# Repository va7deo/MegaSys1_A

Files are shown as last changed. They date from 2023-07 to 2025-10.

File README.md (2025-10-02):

# Jaleco Mega System 1 A FPGA Implementation

FPGA compatible core of Jaleco's Mega System 1 A (P-47 based) arcade hardware for [**MiSTerFPGA**](https://github.com/MiSTer-devel/Main_MiSTer/wiki) written by [**Erin Olafson**] with assistance from [**atrac17**](https://github.com/atrac17). Verified against a authentic P-47: The Freedom Fighter PCB purchased by [**atrac17**](https://github.com/atrac17).

The intent is for this core to be a 1:1 playable implementation of the Mega System 1 A arcade hardware. Currently in **beta state**, this core is in active development. Additional Mega System 1 arcade titles will be in separate repositories (Mega System 1 Rev Z/B/C).

<br>
<p align="center">

</p>

## Supported Titles (Type-A)

| Title | PCB<br>Number | Encrypted<br>Program | MCU | Status | Released |
|---|---|---|-----|---|---|
| [**P-47: The Freedom Fighter**](FILLME) | MB8844<br><br>MB8843 | N/A | N/A | **Implemented** | **20230701** |
| [**Kick Off - Jaleco Cup**](FILLME) | MB8844 | N/A | N/A | **Implemented / W.I.P** | No |
| [**Shingen Samurai-Fighter / Takeda Shingen**](FILLME) | MB8844 | Yes | N/A | **Implemented / W.I.P** | No |
| [**Ninja Kazan / Iga Ninjyutsuden**](FILLME) | MB8845 | Yes | Yes | **Implemented** | **20230923** |
| [**The Astyanax / The Lord of King**](FILLME) | MB8844<br><br>MB8845 | Yes | Yes | **Implemented** | **20230701** |
| [**Hachoo!**](FILLME) | MB8845 | Yes | Yes | **Implemented** | **20240101** |
| [**Jitsuryoku!! Pro Yakyuu**](FILLME) | MBMO2A | Yes | Yes | **Implemented** | **20240106** |
| [**Plus Alpha**](FILLME) | MB8845 | Yes | Yes | **Implemented** | **20240106** |
| [**Saint Dragon**](FILLME) | MB8845 | Yes | Yes | **Implemented** | **20230715** |
| [**Rod-Land**](https://en.wikipedia.org/wiki/Rod_Land) | MBMO2A<br><br>MB8845 | Yes | N/A | **Implemented** | **20230513** |
| [**Phantasm**](FILLME) | MB8845 | Yes | N/A | **Implemented** | **20230708** |
| [**E.D.F: Earth Defense Force (Prototpe)**](FILLME) | W.I.P | Yes | N/A | **Implemented** | **20240101** |
| [**In Your Face (Prototpe)**](FILLME) | W.I.P | Yes | N/A | **Implemented** | **20240101** |
| [**Soldam**](FILLME) | W.I.P | Yes | N/A | **Implemented** | **20230519** |

## External Modules

| Module | Function | Author |
|---|---|---|
| [**fx68k**](https://github.com/ijor/fx68k) | [**Motorola 68000 CPU**](https://en.wikipedia.org/wiki/Motorola_68000) | Jorge Cwik |
| [**fx68k**](https://github.com/ijor/fx68k) | [**Motorola 68000 CPU**](https://en.wikipedia.org/wiki/Motorola_68000) | Jorge Cwik |
| [**jt51**](https://github.com/jotego/jt51) | [**Yamaha YM2151**](https://en.wikipedia.org/wiki/Yamaha_YM2151) | Jose Tejada |
| [**jt6295**](https://github.com/jotego/jt6295) | [**OKI MSM6295**](https://dtsheet.com/doc/957023/oki-m6295) | Jose Tejada |
| [**jt6295**](https://github.com/jotego/jt6295) | [**OKI MSM6295**](https://dtsheet.com/doc/957023/oki-m6295) | Jose Tejada |
| [**yc_out**](https://github.com/MikeS11/MiSTerFPGA_YC_Encoder) | [**Y/C Video Module**](https://en.wikipedia.org/wiki/S-Video) | Mike Simone |
| [**mem**](https://github.com/MiSTer-devel/Arcade-Rygar_MiSTer/tree/master/src/mem) | SDRAM Controller / Rom Downloader | Josh Bassett, modified by Erin Olafson |
| [**core_template**](https://github.com/MiSTer-devel/Template_MiSTer) | MiSTer Framework Template | sorgelig, modified by Erin Olafson / atrac17 |

# Known Issues / Tasks

- ~~OKI playback; correct samples (ROM board dependent)~~  **[Issue]**  

- Mosaic OBJ effects verify against PCB (P-47 JALECO logo)  **[Task]**
- OBJ Scroll effects verify against PCB (P-47 trail effect)  **[Task]**
- ~~Screen flip implementation~~  **[Task]**  
- ~~Verify H-FLIP / V-FLIP for screen flip against PCB~~  **[Task]**
- ~~Program CPU overclock toggle~~  **[Task]**  
- ~~OPM / ADPCM audio mix toggles~~  **[Task]**  
- ~~Verify analog timings from MB8842 mother board~~  **[Task]**  
- ~~Measure HBL, VBL, H-SYNC, and V-SYNC timings from MB8842 mother board~~  **[Task]**  
- ~~64-Bit SDRAM controller access for sprites  **[Task]**~~  

# PCB Check List

## Clock Information

| H-Sync | V-Sync | Source | PCB<br>Number |
|---|---|---|---|
| 15.625kHz | 56.205035 | DSLogic+  | **MB8842** |

## Crystal Oscillators

| Freq (MHz) | Use | PCB<br>Number |
|---|---|---|
| 4.000 MHz  | OKI MSM6295 / MCU CLKS (4 MHz) | **ROM Board<br>(See PCB Number)** |
| 7.000 MHz  | M68000 AUDIO CLOCK (7MHz)<br>YM2151 CLK (3.5 MHz) | **MB8842** |
| 12.000 MHz | M68000 CPU CLK (6 MHz)<br>Pixel CLK (6 MHz) | **MB8842** |

**Pixel clock:** 6.00 MHz

**Estimated geometry:**

    384 pixels/line  
  
    278 lines/frame  

## Main Components

| Chip | Use | PCB Number |
|---|---|---|
| [**Motorola 68000 CPU**](https://en.wikipedia.org/wiki/Motorola_68000) | Main CPU | **MB8842** |
| [**Motorola 68000 CPU**](https://en.wikipedia.org/wiki/Motorola_68000) | Audio CPU | **MB8842** |
| [**Yamaha YM2151**](https://en.wikipedia.org/wiki/Yamaha_YM2151) | OPM Sound | **MB8842** |
| [**OKI MSM6295**](https://dtsheet.com/doc/957023/oki-m6295) | ADPCM Sound | **ROM Board<br>(See PCB Number)** |
| [**OKI MSM6295**](https://dtsheet.com/doc/957023/oki-m6295) | ADPCM Sound | **ROM Board<br>(See PCB Number)** |

### Custom Components

| Chip | Function |
| ---|---|
| **NEC D65005GB200** | Custom Gate-Array / OBJ  |
| **NEC D65005GB249** | Custom Gate-Array / SYNC |
| **NEC D65012GF303** | Custom Gate-Array / VCTR |
| **NEC D65012GF307** | Custom Gate-Array / SCPT | <br>

# Core Features

### Refresh Rate Compatibility Option

- Video timings can be modified if you experience sync issues with CRT or modern displays; this will alter gameplay from it's original state.

| Refresh Rate | Timing Parameter | HTOTAL | VTOTAL |
|---|---|---|---|
| 15.63kHz / 56.2Hz | MB8842 | 384 | 278 |
| 15.63kHz / 59.4Hz | NTSC (Closest Spec)  | 384 | 263 |

- MAME information for timing parameters is incorrect.

| Refresh Rate | Timing Parameter | HTOTAL | VTOTAL |
|---|---|---|---|
| 14.77kHz / 56.2Hz | MAME | 406 | 263 |

### P1/P2 Input Swap Option

- There is a toggle to swap inputs from Player 1 to Player 2. This only swaps inputs for the joystick, it does not effect keyboard inputs.

### Audio Options

- There is a toggle for mixing audio from mono to stereo; MB8842 had this option via dipswitch.

- There are toggles to disable playback of OPM and ADPCM audio or raise the mixing volume the OPM and ADPCM audio channels.

### Overclock Options

- There is a toggle to increase the M68000 frequency from 6MHz to 7.2MHz; this will alter gameplay from it's original state addressing native slowdown of gameplay.

### Native Y/C Output

- Native Y/C ouput is possible with the [**analog I/O rev 6.1 pcb**](https://github.com/MiSTer-devel/Main_MiSTer/wiki/IO-Board). Using the following cables, [**HD-15 to BNC cable**](https://www.amazon.com/StarTech-com-Coax-RGBHV-Monitor-Cable/dp/B0033AF5Y0/) will transmit Y/C over the green and red lines. Choose an appropriate adapter to feed [**Y/C (S-Video)**](https://www.amazon.com/MEIRIYFA-Splitter-Extension-Monitors-Transmission/dp/B09N19XZJQ) to your display.

### H/V Adjustments

- There are two H/V toggles, H/V-sync positioning adjust and H/V-sync width adjust. Positioning will move the display for centering on CRT display. The sync width adjust can be used to for sync issues (rolling, flagging etc) without modifying the video timings.

### Scandoubler Options

- Additional toggle to enable the scandoubler without changing ini settings and new scanline option for 100% is available, this draws a black line every other frame. Below is an example.

<table><tr><th>Scandoubler Fx</th><th>Scanlines 25%</th><th>Scanlines 50%</th><th>Scanlines 75%</th><th>Scanlines 100%</th><tr><td><br> <p align="center"></td><td><br> <p align="center"></td><td><br> <p align="center"></td><td><br> <p align="center"></td><td><br> <p align="center"></td></tr></table> <br>

# PCB Information / Control Layout

| Title | Joystick | Service Menu | Dip Switches | Shared Controls | Dip Default | PCB Information |
|---|---|---|---|---|---|---|
| **P-47: The Freedom Fighter** | 8-Way | **Service Menu** | **Dip Sheet** | Co-Op | N/A | Coming soon |
| **Ninja Kazan / Iga Ninjyutsuden** | 8-Way | **Service Menu** | **Dip Sheet** | Turn Based | N/A | Coming soon |
| **Phantasm** | 8-Way | **Service Menu** | **Dip Sheet** | Turn Based | N/A | Coming soon |
| **Saint Dragon** | 8-Way | **Service Menu** | **Dip Sheet** | Turn Based | N/A | Coming soon |
| **The Astyanax / The Lord of King** | 8-Way | **Service Menu** | **Dip Sheet** | Co-Op | N/A | Coming soon |
| **Rod-Land** | 8-Way | [**Service Menu**](https://github.com/va7deo/MegaSys1_A/assets/32810066/6b35c179-4f39-4044-94f8-8eaaca18737b) | [**Dip Sheet**](https://github.com/va7deo/MegaSys1_A/assets/32810066/4b649233-2e51-460d-b7c9-5a51b3345455) | Co-Op | N/A | Toggling the "Chapter" dipswitch will go from the "First Story (Rescue My Mom)" to the "Second Story (The Unknown Pyramid)". <br><br> You can also insert a coin and press up, up, up, down, down, down, start to enable the second story or up, up, up, down, down, down start to return to the first story on English versions. <br><br> For Japanese versions, the code is reversed for accessing the second story and returning to the first. <br><br> There are three endings to Rod-Land, complete the 31 levels in the first story or second; for the special ending, play either story by inputing the secret code and beating the extra level (32). |
| **Soldam** | 8-Way | [**Service Menu**](https://github.com/va7deo/MegaSys1_A/assets/32810066/57338099-4e76-4973-afb2-7a3141252bb0) | [**Dip Sheet**](https://github.com/va7deo/MegaSys1_A/assets/32810066/0ebbb6b7-2613-4f0e-9174-93e1b2057bd1) | Versus | N/A | Coming soon |
| **Jitsuryoku!! Pro Yakyuu** | 8-Way | **Service Menu** | **Dip Sheet** | Versus | N/A | Coming soon |
| **Hachoo!** | 8-Way | **Service Menu** | **Dip Sheet** | Co-Op | N/A | Coming soon |
| **E.D.F: Earth Defense Force (Prototpe)** | 8-Way | **Service Menu** | **Dip Sheet** | Co-Op | N/A | Coming soon |
| **In Your Face (Prototpe)** | 8-Way | **Service Menu** | **Dip Sheet** | Versus | N/A | Coming soon |
| **Plus Alpha** | 8-Way | **Service Menu** | **Dip Sheet** | Co-Op | N/A | Coming soon |

### Keyboard Handler

<br>

- Keyboard inputs mapped to mame defaults for Player 1 / Player 2.

<br>

|Services|Coin/Start|
|--|--|
|<table> <tr><th>Functions</th><th>Keymap</th></tr><tr><td>Test</td><td>F2</td></tr><tr><td>Reset</td><td>F3</td></tr><tr><td>Service</td><td>9</td></tr><tr><td>Pause</td><td>P</td></tr> </table> | <table><tr><th>Functions</th><th>Keymap</th><tr><tr><td>P1 Start</td><td>1</td></tr><tr><td>P2 Start</td><td>2</td></tr><tr><td>P1 Coin</td><td>5</td></tr><tr><td>P2 Coin</td><td>6</td></tr> </table>|

|Player 1|Player 2|
|--|--|
|<table> <tr><th>Functions</th><th>Keymap</th></tr><tr><td>P1 Up</td><td>Up</td></tr><tr><td>P1 Down</td><td>Down</td></tr><tr><td>P1 Left</td><td>Left</td></tr><tr><td>P1 Right</td><td>Right</td></tr><tr><td>P1 Bttn 1</td><td>L-Ctrl</td></tr><tr><td>P1 Bttn 2</td><td>L-Alt</td></tr><tr><td>P1 Bttn 3</td><td>Space</td></tr><tr><td>P1 Bttn 4</td><td>L-Shift</td></tr> </table> | <table> <tr><th>Functions</th><th>Keymap</th></tr><tr><td>P2 Up</td><td>R</td></tr><tr><td>P2 Down</td><td>F</td></tr><tr><td>P2 Left</td><td>D</td></tr><tr><td>P2 Right</td><td>G</td></tr><tr><td>P2 Bttn 1</td><td>A</td></tr><tr><td>P2 Bttn 2</td><td>S</td></tr><tr><td>P2 Bttn 3</td><td>Q</td></tr><tr><td>P2 Bttn 4</td><td>W</td></tr> </table>|

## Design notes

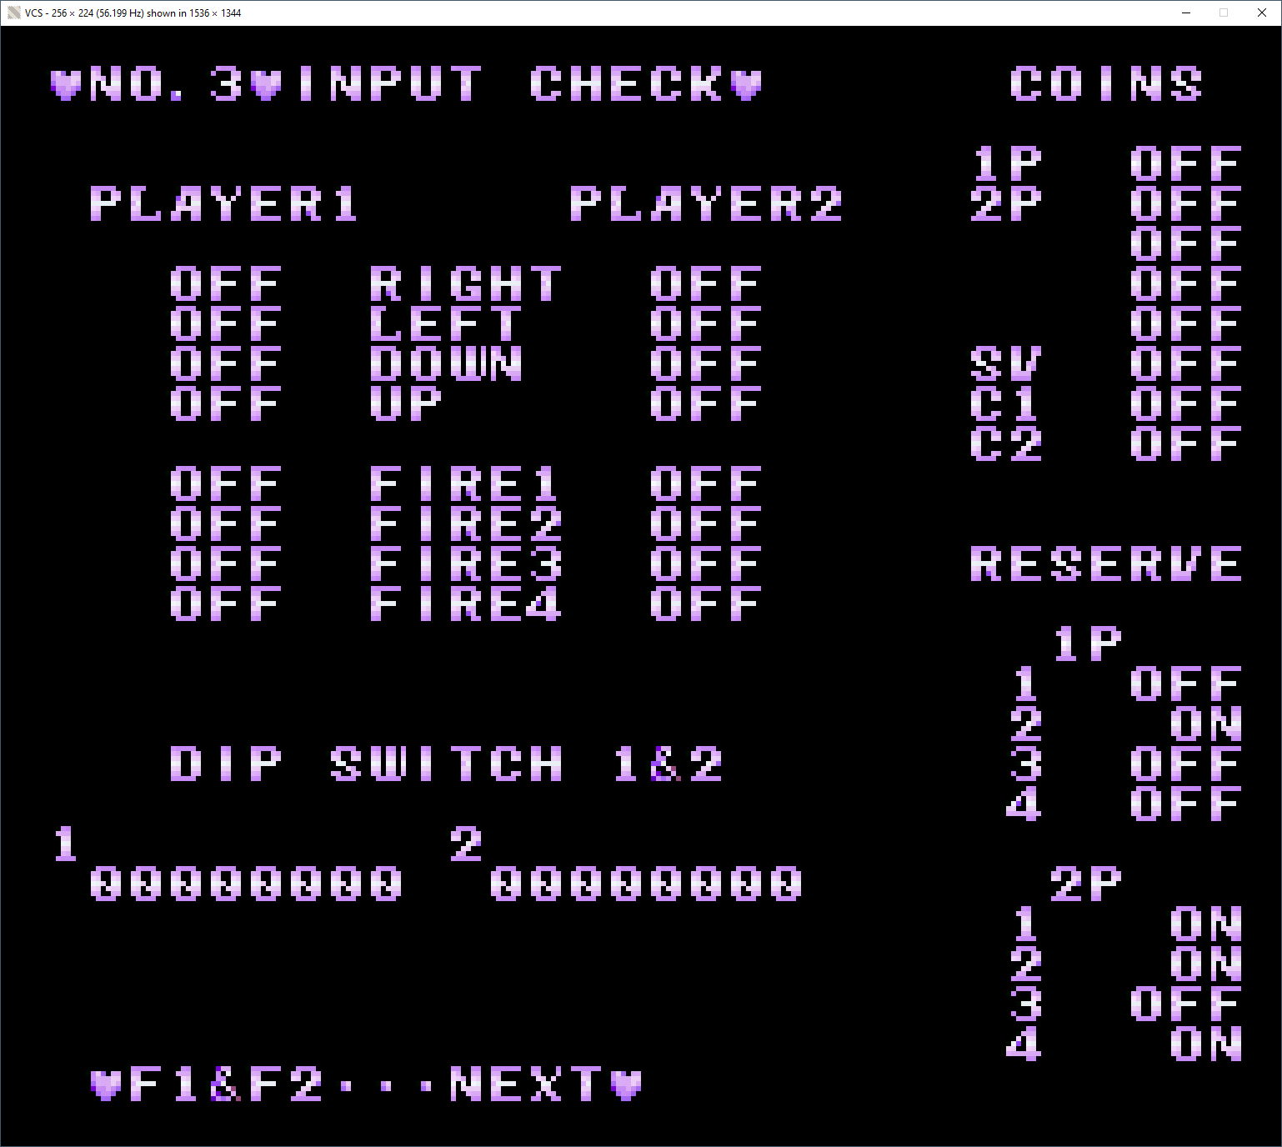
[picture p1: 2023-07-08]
doc/PCB Photos/Reserve_Inputs (p47j).png

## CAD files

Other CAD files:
dev/m68k.stp

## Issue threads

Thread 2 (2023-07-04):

Sync problem

Lagerfeldt, 2023-07-04:
**Problem**
Sync problem/dropout

**Occurs**
Always or every time a game switches between screens, such as Rod-Land from Intro > Title screen > Demo > High score > [...]

**Core tested**
MegaSys1_2023_07_02

**Hardware used**
· Ultimate MiSTer BliSTer Pro Dual RAM
· Eizo 2456 Monitor @ 1920 x 1200 (video_mode=1920,48,32,80,1200,3,6,26,154000) via HDMI
· AOC G2790VXA Monitor VRR @ 1920 x 1080 (video_mode=8) via HDMI

**Other settings**
vsync_adjust=2
refresh_min=49
refresh_max=76

**Other relevant info**
· Core build 2023-05-19 and earlier works - no sync issues. Sync issues occur with or from MegaSys1_2023_07_02
· All other cores work without sync issues on both monitors at different resolutions and refresh rates
· Manually adjusting vsync width in the game can make the problem even worse, i.e. lose sync/signal completely

Anything I can do do test or try out solutions, let me know.

atrac17, 2023-07-05:
Upload your ini file here for me to test. That will be the first thing. Exactly how you are attempting to run the core with your setup now.

Lagerfeldt, 2023-07-05:
Thanks. Uploaded active ini file, zipped. Exactly as is.

[MiSTer.ini.zip](https://github.com/va7deo/MegaSys1_A/files/11955242/MiSTer.ini.zip)

atrac17, 2023-07-06:
I was able to replicate the sync issues using the provided MiSTer.ini and current release build. Commenting the following lines sync doesn't drop with the [MegaSys1_A_20230701.rbf](https://github.com/va7deo/MegaSys1_A/blob/main/releases/MegaSys1_A_20230701.rbf) build.

```
refresh_min=49
refresh_max=76
```

I'm looking at the framework to update the changes. However, I compiled the current source in this repository and sync is stable with the provided ini file. You can either comment out VRR or use this build in the interim, I'll investigate a little further and push changes on the next release.

[MegaSys1_A_20230706.zip](https://github.com/va7deo/MegaSys1_A/files/11968206/MegaSys1_A_20230706.zip)

Lagerfeldt, 2023-07-06:
Thanks! FYI:

**With MegaSys1 A 2023-07-01**
I tried commenting those lines out some days ago in my systematic search for a potential culprit, and it did not fix the problem here. I have tried again just now with no luck as well. To the contrary the makes the sync problem worse, i.e. it loses sync even more or for longer periods.

TL;DR: No change in my setup by commenting out the min/max refresh of the monitor.

**With MegaSys1 A 2023-07-06**
Yes, now it works. But regardless of the refresh min/max. settings - it can be active or commented out in the .ini, it works with this version of the core like the previous versions of the core.

atrac17, 2023-07-06:
That probably has something to do with your individual setup versus mine. I can only go off of what I can replicate. If you run into this problem in the future, you could download quartus 20.1 and click the play button to generate a new rbf file.

Closed 2023-07-06.

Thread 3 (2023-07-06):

potential sync issues with vsync_adjust=1 and vsync_adust=2 on some devices with latest core 20230701

Videodr0me, 2023-07-06:
I noticed that on my LG C9 i get no sync for these titles with vsync_adjust=1 or 2. I know that this might be a weird interaction between the LG C9 and the particulars of these arcade machines timing, but for a couple of reasons i suspect there might be an edge case with this cores timing or the misters vsync adjustment:

1) all cores, no matter how strange their refresh rates/resolutions/dynamic-switching,work with the LG9 and vsync_adjust=2. Even the notorious X68000  core works at nativ refresh rates and dynamic switching. All cores with <62hz work at all resolutionso, cores with refreshrates >62hz work with higher than hd resolutions e.g.: video_mode=1920,48,32,112,1200,3,6,32,154000
This makes this core the only one that does not sync and only works with vsync_adjust=0.

2) Even when the core is set to refresh rate NTSC it does not sync. This is what makes this really strange, as at approx 60hz syncing should be no problem. Even the resolution is not very unique as some other cores use the same. Also Scandoubler FX makes no difference - it will not sync no matter what the settings. Tried at all resolutions, mister.ini at default with only vsync_adjust = 2 and video_mode added. No VRR, no VRR settings in the ini.

3) There were some previous cases where vsync_adjust =2 would produce hdmi streams incompatible with some devices (to tight porches/vblanks/hblanks). Fortunately sorg could fix these in the past. Maybe this is one of those cases.

4) The previous version of the core worked MegaSys1_A_20230519.rbf perfectly with vsync_adjust = 2. The lastest does not. Tested with soldam.

So, this might not be a real bug in the core, but maybe the new timings of the latest core somehow trip the vsync adjustment algorithm. I know that vsync adjust = 2 is stretching the hdmi standard a lot, but maybe this can be easily fixed - maybe even with the old cores timings?

atrac17, 2023-07-06:
This has already been addressed and fixed. Use the build provided here (https://github.com/va7deo/MegaSys1_A/issues/2) in the interim. It has nothing to do with the actual core timings. If the build provided fixes your issue please close.

Thanks!

Videodr0me, 2023-07-07:
The developement version 20230706 (downloaded from a reply to issue#2) fixes this issue. Issue closed.

atrac17, 2023-07-07:
Build tolerance. There is nothing wrong with sync in the core. Thankfully you understood that. All I did was recompile the source before I pushed changes to it yesterday.

Closed 2023-07-07.

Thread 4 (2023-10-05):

Sync problem with latest core

Lmn-San, 2023-10-05:
The previous core (that run Saint Dragon) was working fine on my setup.
Vsync = 2
In game mode -> Native NTSC

latest core (that run Iga ninja)
All previous games black screen and sporadically blink the image (iga included)
vsync = 2
In game: any mode (60 or native, NTSC or PAL)

BTW, my LCD screen accept all frequencies from 47Hz to 75Hz. And all other cores are working fine with vsync = 2

atrac17, 2024-01-06:
Fixed in 72309e4

Closed 2024-01-06.

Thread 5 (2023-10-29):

2nd OKI MSM6295 chip not working in the Soldam core

ruiner9, 2023-10-29:
When running Soldam (latest version, 230923) the 2nd ADPCM channel is inactive. This can be easily verified by entering the soundtest and comparing the music to arcade captures or the OST rip on VGMrips.net. Sound test 03 (VS Mode music) uses both samplers, and turning off the OPM and ADPCM-0 chips in the OSD, leaving ADPSM-1 to play solo results in silence.

atrac17, 2023-10-29:
Will take a look, there seems to be some regressions. Currently bug hunting something else. Thanks!

atrac17, 2024-01-06:
Fixed in https://github.com/va7deo/MegaSys1_A/commit/cfa8f6874d73d850472552631ca5f55db72309e4

Closed 2024-01-06.

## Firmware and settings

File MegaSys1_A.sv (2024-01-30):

//============================================================================
//
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
//============================================================================

`default_nettype none

module emu
(
    //Master input clock
    input         CLK_50M,

    //Async reset from top-level module.
    //Can be used as initial reset.
    input         RESET,

    //Must be passed to hps_io module
    inout  [48:0] HPS_BUS,

    //Base video clock. Usually equals to CLK_SYS.
    output        CLK_VIDEO,

    //Multiple resolutions are supported using different CE_PIXEL rates.
    //Must be based on CLK_VIDEO
    output        CE_PIXEL,

    //Video aspect ratio for HDMI. Most retro systems have ratio 4:3.
    //if VIDEO_ARX[12] or VIDEO_ARY[12] is set then [11:0] contains scaled size instead of aspect ratio.
    output [12:0] VIDEO_ARX,
    output [12:0] VIDEO_ARY,

    output  [7:0] VGA_R,
    output  [7:0] VGA_G,
    output  [7:0] VGA_B,
    output        VGA_HS,
    output        VGA_VS,
    output        VGA_DE,      // = ~(VBlank | HBlank)
    output        VGA_F1,
    output [2:0]  VGA_SL,
    output        VGA_SCALER,  // Force VGA scaler
    output        VGA_DISABLE, // Analog out is off

    input  [11:0] HDMI_WIDTH,
    input  [11:0] HDMI_HEIGHT,
    output        HDMI_FREEZE,

`ifdef MISTER_FB
    // Use framebuffer in DDRAM (USE_FB=1 in qsf)
    // FB_FORMAT:
    //    [2:0] : 011=8bpp(palette) 100=16bpp 101=24bpp 110=32bpp
    //    [3]   : 0=16bits 565 1=16bits 1555
    //    [4]   : 0=RGB  1=BGR (for 16/24/32 modes)
    //
    // FB_STRIDE either 0 (rounded to 256 bytes) or multiple of pixel size (in bytes)
    output        FB_EN,
    output  [4:0] FB_FORMAT,
    output [11:0] FB_WIDTH,
    output [11:0] FB_HEIGHT,
    output [31:0] FB_BASE,
    output [13:0] FB_STRIDE,
    input         FB_VBL,
    input         FB_LL,
    output        FB_FORCE_BLANK,

`ifdef MISTER_FB_PALETTE
    // Palette control for 8bit modes.
    // Ignored for other video modes.
    output        FB_PAL_CLK,
    output  [7:0] FB_PAL_ADDR,
    output [23:0] FB_PAL_DOUT,
    input  [23:0] FB_PAL_DIN,
    output        FB_PAL_WR,
`endif
`endif

    output        LED_USER,  // 1 - ON, 0 - OFF.

    // b[1]: 0 - LED status is system status OR'd with b[0]
    //       1 - LED status is controled solely by b[0]
    // hint: supply 2'b00 to let the system control the LED.
    output  [1:0] LED_POWER,
    output  [1:0] LED_DISK,

    // I/O board button press simulation (active high)
    // b[1]: user button
    // b[0]: osd button
    output  [1:0] BUTTONS,

    //Audio
    input         CLK_AUDIO, // 24.576 MHz
    output [15:0] AUDIO_L,
    output [15:0] AUDIO_R,
    output        AUDIO_S,   // 1 - signed audio samples, 0 - unsigned
    output  [1:0] AUDIO_MIX, // 0 - no mix, 1 - 25%, 2 - 50%, 3 - 100% (mono)

    //ADC
    inout   [3:0] ADC_BUS,

    //SD-SPI
    output        SD_SCK,
    output        SD_MOSI,
    input         SD_MISO,
    output        SD_CS,
    input         SD_CD,

    //High latency DDR3 RAM interface
    //Use for non-critical time purposes
    output        DDRAM_CLK,
    input         DDRAM_BUSY,
    output  [7:0] DDRAM_BURSTCNT,
    output [28:0] DDRAM_ADDR,
    input  [63:0] DDRAM_DOUT,
    input         DDRAM_DOUT_READY,
    output        DDRAM_RD,
    output [63:0] DDRAM_DIN,
    output  [7:0] DDRAM_BE,
    output        DDRAM_WE,

    //SDRAM interface with lower latency
    output        SDRAM_CLK,
    output        SDRAM_CKE,
    output [12:0] SDRAM_A,
    output  [1:0] SDRAM_BA,
    inout  [15:0] SDRAM_DQ,
    output        SDRAM_DQML,
    output        SDRAM_DQMH,
    output        SDRAM_nCS,
    output        SDRAM_nCAS,
    output        SDRAM_nRAS,
    output        SDRAM_nWE,

`ifdef MISTER_DUAL_SDRAM
    //Secondary SDRAM
    //Set all output SDRAM_* signals to Z ASAP if SDRAM2_EN is 0
    input         SDRAM2_EN,
    output        SDRAM2_CLK,
    output [12:0] SDRAM2_A,
    output  [1:0] SDRAM2_BA,
    inout  [15:0] SDRAM2_DQ,
    output        SDRAM2_nCS,
    output        SDRAM2_nCAS,
    output        SDRAM2_nRAS,
    output        SDRAM2_nWE,
`endif

    input         UART_CTS,
    output        UART_RTS,
    input         UART_RXD,
    output        UART_TXD,
    output        UART_DTR,
    input         UART_DSR,

`ifdef MISTER_ENABLE_YC
    output [39:0] CHROMA_PHASE_INC,
    output        YC_EN,
    output        PALFLAG,
`endif

    // Open-drain User port.
    // 0 - D+/RX
    // 1 - D-/TX
    // 2..6 - USR2..USR6
    // Set USER_OUT to 1 to read from USER_IN.
    input   [6:0] USER_IN,
    output  [6:0] USER_OUT,

    input         OSD_STATUS
);

///////// Default values for ports not used in this core /////////

assign ADC_BUS  = 'Z;
assign USER_OUT = 0;
assign {UART_RTS, UART_TXD, UART_DTR} = 0;
assign {SD_SCK, SD_MOSI, SD_CS} = 'Z;
//assign {SDRAM_DQ, SDRAM_A, SDRAM_BA, SDRAM_CLK, SDRAM_CKE, SDRAM_DQML, SDRAM_DQMH, SDRAM_nWE, SDRAM_nCAS, SDRAM_nRAS, SDRAM_nCS} = 'Z;
//assign {DDRAM_CLK, DDRAM_BURSTCNT, DDRAM_ADDR, DDRAM_DIN, DDRAM_BE, DDRAM_RD, DDRAM_WE} = '0;

assign VGA_F1 = 0;
assign VGA_SCALER = 0;
assign HDMI_FREEZE = 0;

assign AUDIO_MIX = 0;
assign LED_USER =  |{ m68kp_a[0], m68ks_a[0], max_count, scroll0_x, scroll0_y, oki0_sample_clk, oki1_sample_clk};
assign LED_DISK = 0;
assign LED_POWER = 0;
assign BUTTONS = 0;

//reg    [7:0] max_count;
//reg   [31:0] req_count;
//reg   [31:0] wait_count;
//reg   [31:0] max_wait;
//reg          prev_cs;

// Status Bit Map:
//              Upper Case                     Lower Case           
// 0         1         2         3          4         5         6   
// 01234567890123456789012345678901 23456789012345678901234567890123
// 0123456789ABCDEFGHIJKLMNOPQRSTUV 0123456789ABCDEFGHIJKLMNOPQRSTUV
// X  XXXXXXXXXXX     X X XXXXXXXXX XXXXXXXXXXXXXXXXXX      XXXXXXXX

wire [1:0] aspect_ratio = status[9:8];
wire       orientation  = ~status[3];
wire [2:0] scan_lines   = status[6:4];
reg        refresh_mod;
reg        new_vmode;

always @(posedge clk_sys) begin
    if (refresh_mod != status[19]) begin
        refresh_mod <= status[19];
        new_vmode <= ~new_vmode;
    end
end

wire [3:0] hs_offset = status[27:24];
wire [3:0] vs_offset = status[31:28];
wire [3:0] hs_width  = status[59:56];
wire [3:0] vs_width  = status[63:60];

assign VIDEO_ARX = (!aspect_ratio) ? (orientation  ? 8'd8 : 8'd7) : (aspect_ratio - 1'd1);
assign VIDEO_ARY = (!aspect_ratio) ? (orientation  ? 8'd7 : 8'd8) : 12'd0;
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

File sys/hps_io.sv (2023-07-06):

//
// hps_io.v
//
// Copyright (c) 2014 Till Harbaum <till@harbaum.org>
// Copyright (c) 2017-2020 Alexey Melnikov
//
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
///////////////////////////////////////////////////////////////////////
// altera message_off 10665

//
// Use buffer to access SD card. It's time-critical part.
//
// WIDE=1 for 16 bit file I/O
// VDNUM 1..10
// BLKSZ 0..7: 0 = 128, 1 = 256, 2 = 512(default), .. 7 = 16384
//
module hps_io #(parameter CONF_STR, CONF_STR_BRAM=1, PS2DIV=0, WIDE=0, VDNUM=1, BLKSZ=2, PS2WE=0)
(
	input             clk_sys,
	inout      [48:0] HPS_BUS,

	// buttons up to 32
	output reg [31:0] joystick_0,
	output reg [31:0] joystick_1,
	output reg [31:0] joystick_2,
	output reg [31:0] joystick_3,
	output reg [31:0] joystick_4,
	output reg [31:0] joystick_5,
	
	// analog -127..+127, Y: [15:8], X: [7:0]
	output reg [15:0] joystick_l_analog_0,
	output reg [15:0] joystick_l_analog_1,
	output reg [15:0] joystick_l_analog_2,
	output reg [15:0] joystick_l_analog_3,
	output reg [15:0] joystick_l_analog_4,
	output reg [15:0] joystick_l_analog_5,

	output reg [15:0] joystick_r_analog_0,
	output reg [15:0] joystick_r_analog_1,
	output reg [15:0] joystick_r_analog_2,
	output reg [15:0] joystick_r_analog_3,
	output reg [15:0] joystick_r_analog_4,
	output reg [15:0] joystick_r_analog_5,

	input      [15:0] joystick_0_rumble, // 15:8 - 'large' rumble motor magnitude, 7:0 'small' rumble motor magnitude
	input      [15:0] joystick_1_rumble,
	input      [15:0] joystick_2_rumble,
	input      [15:0] joystick_3_rumble,
	input      [15:0] joystick_4_rumble,
	input      [15:0] joystick_5_rumble,

	// paddle 0..255
	output reg  [7:0] paddle_0,
	output reg  [7:0] paddle_1,
	output reg  [7:0] paddle_2,
	output reg  [7:0] paddle_3,
	output reg  [7:0] paddle_4,
	output reg  [7:0] paddle_5,

	// spinner [7:0] -128..+127, [8] - toggle with every update
	output reg  [8:0] spinner_0,
	output reg  [8:0] spinner_1,
	output reg  [8:0] spinner_2,
	output reg  [8:0] spinner_3,
	output reg  [8:0] spinner_4,
	output reg  [8:0] spinner_5,

	// ps2 keyboard emulation
	output            ps2_kbd_clk_out,
	output            ps2_kbd_data_out,
	input             ps2_kbd_clk_in,
	input             ps2_kbd_data_in,

	input       [2:0] ps2_kbd_led_status,
	input       [2:0] ps2_kbd_led_use,

	output            ps2_mouse_clk_out,
	output            ps2_mouse_data_out,
	input             ps2_mouse_clk_in,
	input             ps2_mouse_data_in,

	// ps2 alternative interface.

	// [8] - extended, [9] - pressed, [10] - toggles with every press/release
	output reg [10:0] ps2_key = 0,

	// [24] - toggles with every event
	output reg [24:0] ps2_mouse = 0,
	output reg [15:0] ps2_mouse_ext = 0, // 15:8 - reserved(additional buttons), 7:0 - wheel movements

	output      [1:0] buttons,
	output            forced_scandoubler,
	output            direct_video,
	input             video_rotated,

	//toggle to force notify of video mode change
	input             new_vmode,

	inout      [21:0] gamma_bus,

	output reg [63:0] status,
	input      [63:0] status_in,
	input             status_set,
	input      [15:0] status_menumask,

	input             info_req,
	input       [7:0] info,

	// SD config
	output reg [VD:0] img_mounted,  // signaling that new image has been mounted
	output reg        img_readonly, // mounted as read only. valid only for active bit in img_mounted
	output reg [63:0] img_size,     // size of image in bytes. valid only for active bit in img_mounted

	// SD block level access
	input      [31:0] sd_lba[VDNUM],
	input       [5:0] sd_blk_cnt[VDNUM], // number of blocks-1, total size ((sd_blk_cnt+1)*(1<<(BLKSZ+7))) must be <= 16384!
	input      [VD:0] sd_rd,
	input      [VD:0] sd_wr,
	output reg [VD:0] sd_ack,

	// SD byte level access. Signals for 2-PORT altsyncram.
	output reg [AW:0] sd_buff_addr,
	output reg [DW:0] sd_buff_dout,
	input      [DW:0] sd_buff_din[VDNUM],
	output reg        sd_buff_wr,

	// ARM -> FPGA download
	output reg        ioctl_download = 0, // signal indicating an active download
	output reg [15:0] ioctl_index,        // menu index used to upload the file
	output reg        ioctl_wr,
	output reg [26:0] ioctl_addr,         // in WIDE mode address will be incremented by 2
	output reg [DW:0] ioctl_dout,
	output reg        ioctl_upload = 0,   // signal indicating an active upload
	input             ioctl_upload_req,   // request to save (must be supported on HPS side for specific core)
	input       [7:0] ioctl_upload_index,
	input      [DW:0] ioctl_din,
	output reg        ioctl_rd,
	output reg [31:0] ioctl_file_ext,
	input             ioctl_wait,

	// [15]: 0 - unset, 1 - set. [1:0]: 0 - none, 1 - 32MB, 2 - 64MB, 3 - 128MB
	// [14]: debug mode: [8]: 1 - phase up, 0 - phase down. [7:0]: amount of shift.
	output reg [15:0] sdram_sz,

	// RTC MSM6242B layout
	output reg [64:0] RTC,

	// Seconds since 1970-01-01 00:00:00
	output reg [32:0] TIMESTAMP,

	// UART flags
	output reg  [7:0] uart_mode,
	output reg [31:0] uart_speed,

	// for core-specific extensions
	inout      [35:0] EXT_BUS
);

assign EXT_BUS[31:16] = HPS_BUS[31:16];
assign EXT_BUS[35:33] = HPS_BUS[35:33];

localparam DW = (WIDE) ? 15 : 7;
localparam AW = (WIDE) ? 12 : 13;
localparam VD = VDNUM-1;

wire        io_strobe= HPS_BUS[33];
wire        io_enable= HPS_BUS[34];
wire        fp_enable= HPS_BUS[35];
wire        io_wide  = (WIDE) ? 1'b1 : 1'b0;
wire [15:0] io_din   = HPS_BUS[31:16];
reg  [15:0] io_dout;

assign HPS_BUS[37]   = ioctl_wait;
assign HPS_BUS[36]   = clk_sys;
assign HPS_BUS[32]   = io_wide;
assign HPS_BUS[15:0] = EXT_BUS[32] ? EXT_BUS[15:0] : fp_enable ? fp_dout : io_dout;

reg [15:0] cfg;
assign buttons = cfg[1:0];
//cfg[2] - vga_scaler handled in sys_top
//cfg[3] - csync handled in sys_top
assign forced_scandoubler = cfg[4];
//cfg[5] - ypbpr handled in sys_top
assign direct_video = cfg[10];

reg [3:0] sdn;
reg [3:0] sd_rrb = 0;
always_comb begin
	int n, i;

	sdn = 0;
   for(i = VDNUM - 1; i >= 0; i = i - 1) begin
		n = i + sd_rrb;
		if(n >= VDNUM) n = n - VDNUM;
		if(sd_wr[n] | sd_rd[n]) sdn = n[3:0];
   end
end

/////////////////////////////////////////////////////////

wire [15:0] vc_dout;
video_calc video_calc
(
	.clk_100(HPS_BUS[43]),
	.clk_vid(HPS_BUS[42]),
	.clk_sys(clk_sys),
	.ce_pix(HPS_BUS[41]),
	.de(HPS_BUS[40]),
	.hs(HPS_BUS[39]),
	.vs(HPS_BUS[38]),
	.vs_hdmi(HPS_BUS[44]),
	.f1(HPS_BUS[45]),
	.new_vmode(new_vmode),
	.video_rotated(video_rotated),

	.par_num(byte_cnt[3:0]),
	.dout(vc_dout)
);

/////////////////////////////////////////////////////////

localparam STRLEN = $size(CONF_STR)>>3;
localparam MAX_W = $clog2((32 > (STRLEN+2)) ? 32 : (STRLEN+2))-1;

wire [7:0] conf_byte;
generate
	if(CONF_STR_BRAM) begin
		confstr_rom #(CONF_STR, STRLEN) confstr_rom(.*, .conf_addr(byte_cnt - 1'd1));
	end
	else begin
		assign conf_byte = CONF_STR[{(STRLEN - byte_cnt),3'b000} +:8];
	end
endgenerate
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

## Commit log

2023-05-13 Rod-Land Beta 20230513
    [m68k.stp]
2023-05-13 P-47 PCB Photos
2023-05-15 Corrected Video Timings
    Not reported accurately in MAME, taken from PCB. This should resolve #1.
2023-06-30 Fix oki rom addressing & add ym2151 to ipl2, updated audio mix. Inputs set per MB8842 PCB. Add MCU & fix 8x8 scroll addressing for ASTYANAX. vblank & dtackn updated.
    MRA files will need to reflect new inputs. Will push update with beta.
    [MegaSys1_A.sv]
2023-07-01 Fix sprite buffer erasing. Sprites show in first couple of scanlines now.
    [MegaSys1_A.sv]
2023-07-01 Fix oki playback after adding irq scanline to MRA. P-47 reserve inputs mapped per PCB. Audio levels match PCB.
    [MegaSys1_A.sv]
2024-01-04 Prep for Plus Alpha (See Notes)
    Address issue #4
    Address issue #5
    Screen Flip Implementation
    Adjust Clocking and add latch
    Fix reset bug
    Only build with Quartus 20.01, screen tearing occurs with previous and newer versions of Quartus
    [MegaSys1_A.sv]

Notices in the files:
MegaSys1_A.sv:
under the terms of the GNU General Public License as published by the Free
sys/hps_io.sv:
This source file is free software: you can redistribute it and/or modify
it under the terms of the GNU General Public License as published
